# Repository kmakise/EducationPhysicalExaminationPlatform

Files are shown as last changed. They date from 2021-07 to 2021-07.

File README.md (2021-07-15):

# EducationPhysicalExaminationPlatform
基于STM32 RK3399的智能体检试验台 
## 上位
使用基于RK3399的Android工控平板作为交互终端
## 下位
使用基于STM32核FreeRTOS作为传感器驱动和数据上传
## 传感器
非接触式温度传感器：MLX90615
距离传感器： 夏普红外GP2Y0A
血氧浓度传感器：MAX30100
称重传感器：HX711+RB
烟雾触传感器：MQ-2
环境温湿度传感器:DHT11
光照度传感器：BH1750

# 图片
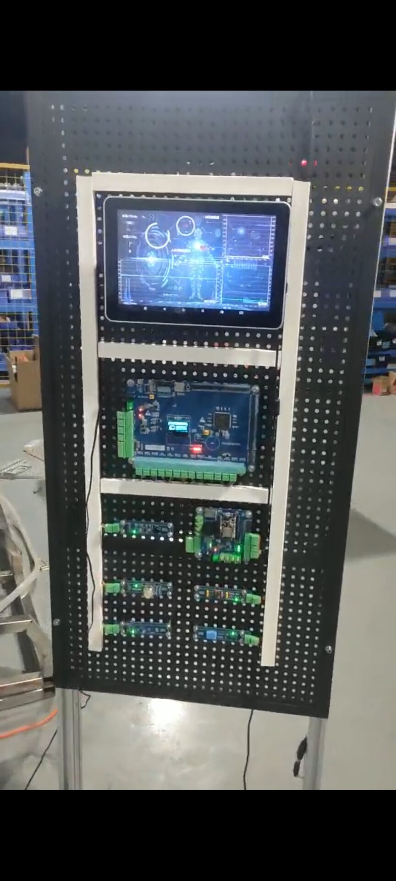
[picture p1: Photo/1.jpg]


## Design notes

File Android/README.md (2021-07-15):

# USB-OTG-CH340-UART-interface

USB-OTG-CH340-UART-interface that is a library communication with USB convert uart, that module is ch340 model, it not need root of your phone.

## License

```
   Copyright (C) [2018] [x-sir, USB-OTG-CH340-UART-interface Open Source Project]

   Licensed under the Apache License, Version 2.0 (the "License");
   you may not use this file except in compliance with the License.
   You may obtain a copy of the License at

       http://www.apache.org/licenses/LICENSE-2.0

   Unless required by applicable law or agreed to in writing, software
   distributed under the License is distributed on an "AS IS" BASIS,
   WITHOUT WARRANTIES OR CONDITIONS OF ANY KIND, either express or implied.
   See the License for the specific language governing permissions and
   limitations under the License.

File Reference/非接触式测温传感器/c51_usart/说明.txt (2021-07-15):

/*
Keil:uVision2
MCU:STC90C516RD+
硬件接法：
GY-MCU90614---STM32
1、GY-MCU90614_RX---STM32_TX,STM32复位将发送A5 45 EA给模块
2、STM32_TX---FT232,STM32将数据上传给上位机
3、GY-MCU90614_TX---STM32_RX，接收模块温度数据
软件说明:
该程序采用串口方式获取模块角度数据，波特率9600
所以得用上位机先将模块串口设置成9600，然后再进行以上操作：
指令:A5 AE 53,模块需复位生效

注：中断函数位于stc_it.c
联系方式：
http://shop62474960.taobao.com/?spm=a230r.7195193.1997079397.2.9qa3Ky&v=1

15.6.27
*/

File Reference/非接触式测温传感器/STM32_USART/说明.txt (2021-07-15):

/*
Keil: MDK5.10.0.2
MCU:stm32f103c8
硬件接法：
GY-MCU90614---STM32
1、GY-MCU90614_RX---STM32_TX,STM32复位将发送A5 45 EA给模块
2、STM32_TX---FT232,STM32将数据上传给上位机
3、GY-MCU90614_TX---STM32_RX，接收模块温度数据
软件说明:
该程序采用串口方式获取模块角度数据，波特率115200,
需要先修改模块或者单片机波特率对应一致。

联系方式：
http://shop62474960.taobao.com/?spm=a230r.7195193.1997079397.2.9qa3Ky&v=1
注：中断函数位于stm32f10x_it.c
15.6.27
*/

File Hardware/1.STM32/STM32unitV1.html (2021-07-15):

Altium customize

# Board Information Report

Date: | | 2021/1/8
Time: | | 13:16:20
Elapsed Time: | | 00:00:01
Filename: | | C:\Users\17122\Desktop\教学仪器\PCB\1.STM32-主控单元\STM32unit\STM32unitV1.PcbDoc
Units: | | mmmils

## Contents

Contents

Board Specification

General

Routing

Routing Information

Layer Information

Layer Information

Drill Pairs

Copper Area

Copper Area

Board Holes

Non-Plated Hole Size

Plated Hole Size

Board Slots

Non-Plated Slot Size

Plated Slot Size

Board Square Holes

Non-Plated Square Hole Size

Plated Square Hole Size

Other

Top Layer Annular Ring Size

Mid Layer Annular Ring Size

Bottom Layer Annular Ring Size

Pad Solder Mask

Pad Paste Mask

Pad Pwr/Gnd Expansion

Pad Relief Conductor Width

Pad Relief Air Gap

Pad Relief Entries

Via Solder Mask

Via Pwr/Gnd Expansion

Track Width

Arc Line Width

Arc Radius

Arc Degrees

Text Height

Text Width

Net Track Width

Net Via Size

## Board Specification

General
Board Size | 206mm x 142mm
Components on board | 234

Back to top

## Routing

Routing Information
Routing completion | 100.00%
Connections | 692
Connections routed | 692
Connections remaining | 0

Back to top

## Layer Information

Layer | Arcs | Pads | Vias | Tracks | Texts | Fills | Regions | ComponentBodies
Top Layer | 0 | 617 | 0 | 2739 | 0 | 0 | 65 | 0
Bottom Layer | 0 | 0 | 0 | 732 | 0 | 0 | 11 | 0
Mechanical 1 | 2 | 0 | 0 | 0 | 0 | 0 | 0 | 36
Mechanical 8 | 0 | 0 | 0 | 0 | 0 | 0 | 0 | 2
Mechanical 13 | 1742 | 0 | 0 | 32 | 0 | 0 | 0 | 225
Mechanical 15 | 169 | 0 | 0 | 370 | 0 | 0 | 0 | 0
Multi-Layer | 0 | 309 | 892 | 0 | 0 | 0 | 1 | 0
Top Paste | 0 | 4 | 0 | 0 | 0 | 0 | 0 | 0
Top Overlay | 40 | 0 | 0 | 2114 | 683 | 42 | 0 | 0
Top Solder | 0 | 0 | 0 | 0 | 0 | 0 | 0 | 0
Bottom Solder | 0 | 0 | 0 | 0 | 0 | 0 | 0 | 0
Bottom Overlay | 0 | 0 | 0 | 4 | 0 | 0 | 0 | 0
Bottom Paste | 0 | 0 | 0 | 0 | 0 | 0 | 0 | 0
Drill Guide | 0 | 0 | 0 | 0 | 0 | 0 | 0 | 0
Keep-Out Layer | 4 | 0 | 0 | 4 | 0 | 0 | 0 | 0
Drill Drawing | 0 | 0 | 0 | 0 | 0 | 0 | 0 | 0
Total | 1957 | 930 | 892 | 5995 | 683 | 42 | 77 | 263

Back to top

Drill Pairs | Vias
Top Layer - Bottom Layer | 892
Total | 892

Back to top

## Copper Area

Layer | Sq.In. | Sq.MM. | Percent of layer
Top Layer | 36.196 | 23351.938 | 80%
Bottom Layer | 41.461 | 26749.029 | 92%
Total | 77.657 | 50100.967

Back to top

## Board Holes

Non-Plated Hole Size | Pads | Vias
0.75mm | 2 | 0
Total | 2 | 0

Back to top

Plated Hole Size | Pads | Vias
0mm | 614 | 0
0.3mm | 0 | 862
0.6mm | 2 | 0
0.711mm | 0 | 30
0.85mm | 2 | 0
0.9mm | 202 | 0
1.1mm | 84 | 0
1.2mm | 2 | 0
1.27mm | 2 | 0
5.2mm | 4 | 0
Total | 912 | 892

Back to top

## Board Slots

Non-Plated Slot Size / Length | Pads
Total | 0

Back to top

Plated Slot Size / Length | Pads
23.622mil / 51.181mil | 2
31.496mil / 55.118mil | 2
31.496mil / 62.991mil | 1
31.496mil / 62.993mil | 1
31.496mil / 118.11mil | 1
31.496mil / 98.425mil | 1
31.496mil / 118.11mil | 1
Total | 9

Back to top

## Board Square Holes

Non-Plated Square Hole Size | Pads
Total | 0

Back to top

Plated Square Hole Size | Pads
Total | 0

Back to top

## Other

Top Layer Annular Ring Size | Count
0mm | 2
0.3mm | 862
0.4mm | 4
0.42mm | 2
0.559mm | 30
0.6mm | 144
0.7mm | 8
0.7mm | 2
0.8mm | 48
0.9mm | 2
0.9mm | 84
1.15mm | 2
1.2mm | 1
1.2mm | 1
1.3mm | 2
3.2mm | 1
3.81mm | 2
6.8mm | 4
Total | 1201

Back to top

Mid Layer Annular Ring Size | Count
0mm | 2
0.3mm | 862
0.4mm | 4
0.42mm | 2
0.559mm | 30
0.6mm | 144
0.7mm | 8
0.7mm | 2
0.8mm | 48
0.9mm | 2
0.9mm | 84
1.15mm | 2
1.2mm | 1
1.2mm | 1
1.3mm | 2
3.2mm | 1
3.81mm | 2
6.8mm | 4
Total | 1201

Back to top

Bottom Layer Annular Ring Size | Count
0mm | 2
0.3mm | 862
0.4mm | 4
0.42mm | 2
0.559mm | 30
0.6mm | 144
0.7mm | 8
0.7mm | 2
0.8mm | 48
0.9mm | 2
0.9mm | 84
1.15mm | 2
1.2mm | 1
1.2mm | 1
1.3mm | 2
3.2mm | 1
3.81mm | 2
6.8mm | 4
Total | 1201

Back to top

Pad Solder Mask | Count
0.1016mm | 930
Total | 930

Back to top

Pad Paste Mask | Count
0mm | 930
Total | 930

Back to top

Pad Pwr/Gnd Expansion | Count
0.508mm | 930
Total | 930

Back to top

Pad Relief Conductor Width | Count
0.254mm | 930
Total | 930

Back to top

Pad Relief Air Gap | Count
0.254mm | 930
Total | 930

Back to top

Pad Relief Entries | Count
4 | 930
Total | 930

Back to top

Via Solder Mask | Count
0.0254mm | 892
Total | 892

Back to top

Via Pwr/Gnd Expansion | Count
0.508mm | 892
Total | 892

Back to top

Track Width | Count
0.0254mm | 50
0.05mm | 292
0.1mm | 52
0.127mm | 50
0.129mm | 2
0.15mm | 4
0.1524mm | 820
0.2mm | 408
0.2032mm | 435
0.254mm | 3514
0.3048mm | 1
0.35mm | 1
0.381mm | 2
0.6mm | 16
0.8mm | 326
2mm | 6
2.54mm | 16
Total | 5995

Back to top

Arc Line Width | Count
0.0254mm | 25
0.05mm | 144
0.1mm | 1
0.127mm | 2
0.129mm | 1
0.15mm | 1
0.2mm | 1762
0.2032mm | 4
0.25mm | 8
0.254mm | 7
0.5mm | 1
0.6mm | 1
Total | 1957

Back to top

Arc Radius | Count
0.1016mm | 1
0.1136mm | 1
0.125mm | 8
0.127mm | 25
0.1545mm | 1
0.2016mm | 1
0.3mm | 1
0.35mm | 144
0.3592mm | 1
0.381mm | 2
0.5mm | 4
0.508mm | 2
1.1903mm | 16
2.2468mm | 1
2.325mm | 2
2.3899mm | 1
3mm | 1740
4.6mm | 1
7mm | 2
7mm | 2
10.8509mm | 1
Total | 1957

Back to top

Arc Degrees | Count
45 | 1
90 | 6
100 | 16
180 | 2
182 | 2
360 | 1930
Total | 1957

Back to top

Text Height | Count
1.27mm | 2
1.524mm | 470
2mm | 2
2.3mm | 2
2.54mm | 169
3mm | 7
3.5mm | 29
4mm | 1
5mm | 1
Total | 683

Back to top

Text Width | Count
0.1016mm | 2
0.1524mm | 4
0.254mm | 677
Total | 683

Back to top

Net Track Width | Count
0.127mm | 216
Total | 216

Back to top

Net Via Size | Count
0.6mm | 216
Total | 216

Back to top

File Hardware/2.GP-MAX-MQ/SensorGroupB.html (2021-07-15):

Altium customize

# Board Information Report

Date: | | 2021/1/14
Time: | | 15:26:07
Elapsed Time: | | 00:00:01
Filename: | | C:\Users\17122\Desktop\教学仪器\PCB\GP-MAX-MQ\SensorGroupB.PcbDoc
Units: | | mmmils

## Contents

Contents

Board Specification

General

Routing

Routing Information

Layer Information

Layer Information

Drill Pairs

Copper Area

Copper Area

Board Holes

Non-Plated Hole Size

Plated Hole Size

Board Slots

Non-Plated Slot Size

Plated Slot Size

Board Square Holes

Non-Plated Square Hole Size

Plated Square Hole Size

Other

Top Layer Annular Ring Size

Mid Layer Annular Ring Size

Bottom Layer Annular Ring Size

Pad Solder Mask

Pad Paste Mask

Pad Pwr/Gnd Expansion

Pad Relief Conductor Width

Pad Relief Air Gap

Pad Relief Entries

Via Solder Mask

Via Pwr/Gnd Expansion

Track Width

Arc Line Width

Arc Radius

Arc Degrees

Text Height

Text Width

Net Track Width

Net Via Size

## Board Specification

General
Board Size | 99.5mm x 79mm
Components on board | 24

Back to top

## Routing

Routing Information
Routing completion | 90.91%
Connections | 55
Connections routed | 50
Connections remaining | 5

Back to top

## Layer Information

Layer | Arcs | Pads | Vias | Tracks | Texts | Fills | Regions | ComponentBodies
Top Layer | 0 | 34 | 0 | 140 | 0 | 0 | 0 | 0
Bottom Layer | 0 | 0 | 0 | 9 | 0 | 0 | 3 | 0
Mechanical 1 | 0 | 0 | 0 | 0 | 0 | 0 | 0 | 6
Mechanical 13 | 0 | 0 | 0 | 0 | 0 | 0 | 0 | 32
Mechanical 15 | 10 | 0 | 0 | 20 | 0 | 0 | 0 | 0
Multi-Layer | 0 | 46 | 9 | 0 | 0 | 0 | 26 | 0
Top Paste | 0 | 0 | 0 | 0 | 0 | 0 | 0 | 0
Top Overlay | 7 | 0 | 0 | 272 | 102 | 6 | 0 | 0
Top Solder | 0 | 0 | 0 | 0 | 0 | 0 | 0 | 0
Bottom Solder | 0 | 0 | 0 | 0 | 0 | 0 | 0 | 0
Bottom Overlay | 0 | 0 | 0 | 0 | 0 | 0 | 0 | 0
Bottom Paste | 0 | 0 | 0 | 0 | 0 | 0 | 0 | 0
Drill Guide | 0 | 0 | 0 | 0 | 0 | 0 | 0 | 0
Keep-Out Layer | 37 | 0 | 0 | 24 | 0 | 0 | 0 | 0
Drill Drawing | 0 | 0 | 0 | 0 | 0 | 0 | 0 | 0
Total | 54 | 80 | 9 | 465 | 102 | 6 | 29 | 38

Back to top

Drill Pairs | Vias
Top Layer - Bottom Layer | 9
Total | 9

Back to top

## Copper Area

Layer | Sq.In. | Sq.MM. | Percent of layer
Top Layer | 0.992 | 640.177 | 8%
Bottom Layer | 4.947 | 3191.518 | 42%
Total | 5.939 | 3831.695

Back to top

## Board Holes

Non-Plated Hole Size | Pads | Vias
Total | 0 | 0

Back to top

Plated Hole Size | Pads | Vias
0mm | 34 | 0
0.7112mm | 0 | 9
0.9mm | 22 | 0
1.1mm | 12 | 0
5.2mm | 12 | 0
Total | 80 | 9

Back to top

## Board Slots

Non-Plated Slot Size / Length | Pads
Total | 0

Back to top

Plated Slot Size / Length | Pads
Total | 0

Back to top

## Board Square Holes

Non-Plated Square Hole Size | Pads
Total | 0

Back to top

Plated Square Hole Size | Pads
Total | 0

Back to top

## Other

Top Layer Annular Ring Size | Count
0.5588mm | 9
0.8mm | 22
0.9mm | 12
2.8mm | 12
Total | 55

Back to top

Mid Layer Annular Ring Size | Count
0.5588mm | 9
0.8mm | 22
0.9mm | 12
2.8mm | 12
Total | 55

Back to top

Bottom Layer Annular Ring Size | Count
0.5588mm | 9
0.8mm | 22
0.9mm | 12
2.8mm | 12
Total | 55

Back to top

Pad Solder Mask | Count
0.1016mm | 80
Total | 80

Back to top

Pad Paste Mask | Count
0mm | 80
Total | 80

Back to top

Pad Pwr/Gnd Expansion | Count
0.508mm | 80
Total | 80

Back to top

Pad Relief Conductor Width | Count
0.254mm | 80
Total | 80

Back to top

Pad Relief Air Gap | Count
0.254mm | 80
Total | 80

Back to top

Pad Relief Entries | Count
4 | 80
Total | 80

Back to top

Via Solder Mask | Count
0.0254mm | 9
Total | 9

Back to top

Via Pwr/Gnd Expansion | Count
0.508mm | 9
Total | 9

Back to top

Track Width | Count
0.0254mm | 2
0.05mm | 18
0.1524mm | 111
0.2mm | 32
0.2032mm | 6
0.254mm | 147
0.381mm | 149
Total | 465

Back to top

Arc Line Width | Count
0.0254mm | 1
0.05mm | 9
0.2mm | 6
0.254mm | 37
1mm | 1
Total | 54

Back to top

Arc Radius | Count
0.127mm | 1
0.35mm | 9
0.508mm | 1
1.1981mm | 2
1.5mm | 6
1.6mm | 18
2mm | 2
3mm | 1
3.5mm | 2
4mm | 12
Total | 54

Back to top

Arc Degrees | Count
90 | 12
180 | 2
360 | 40
Total | 54

Back to top

Text Height | Count
1.27mm | 3
1.524mm | 48
2mm | 27
3mm | 12
4mm | 8
6mm | 4
Total | 102

Back to top

Text Width | Count
0.1524mm | 3
0.254mm | 99
Total | 102

Back to top

Net Track Width | Count
0.127mm | 13
Total | 13

Back to top

Net Via Size | Count
0.6mm | 13
Total | 13

Back to top

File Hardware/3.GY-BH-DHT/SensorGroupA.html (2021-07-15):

Altium customize

# Board Information Report

Date: | | 2021/1/13
Time: | | 20:07:42
Elapsed Time: | | 00:00:01
Filename: | | C:\Users\17122\Desktop\教学仪器\PCB\2.体温-温湿度-光照\GY-BH-DHT\SensorGroupA.PcbDoc
Units: | | mmmils

## Contents

Contents

Board Specification

General

Routing

Routing Information

Layer Information

Layer Information

Drill Pairs

Copper Area

Copper Area

Board Holes

Non-Plated Hole Size

Plated Hole Size

Board Slots

Non-Plated Slot Size

Plated Slot Size

Board Square Holes

Non-Plated Square Hole Size

Plated Square Hole Size

Other

Top Layer Annular Ring Size

Mid Layer Annular Ring Size

Bottom Layer Annular Ring Size

Pad Solder Mask

Pad Paste Mask

Pad Pwr/Gnd Expansion

Pad Relief Conductor Width

Pad Relief Air Gap

Pad Relief Entries

Via Solder Mask

Via Pwr/Gnd Expansion

Track Width

Arc Line Width

Arc Radius

Arc Degrees

Text Height

Text Width

Net Track Width

Net Via Size

## Board Specification

General
Board Size | 99.5mm x 79mm
Components on board | 47

Back to top

## Routing

Routing Information
Routing completion | 95.28%
Connections | 106
Connections routed | 101
Connections remaining | 5

Back to top

## Layer Information

Layer | Arcs | Pads | Vias | Tracks | Texts | Fills | Regions | ComponentBodies
Top Layer | 0 | 103 | 0 | 306 | 0 | 0 | 0 | 0
Bottom Layer | 0 | 0 | 0 | 34 | 0 | 0 | 3 | 0
Mechanical 1 | 0 | 0 | 0 | 0 | 0 | 0 | 0 | 6
Mechanical 13 | 1 | 0 | 0 | 44 | 0 | 0 | 0 | 51
Mechanical 15 | 25 | 0 | 0 | 78 | 0 | 0 | 0 | 0
Multi-Layer | 0 | 46 | 38 | 0 | 0 | 0 | 19 | 0
Top Paste | 0 | 0 | 0 | 0 | 0 | 0 | 0 | 0
Top Overlay | 24 | 0 | 0 | 429 | 143 | 6 | 0 | 0
Top Solder | 0 | 0 | 0 | 0 | 0 | 0 | 0 | 0
Bottom Solder | 0 | 0 | 0 | 0 | 0 | 0 | 0 | 0
Bottom Overlay | 0 | 0 | 0 | 0 | 0 | 0 | 0 | 0
Bottom Paste | 0 | 0 | 0 | 0 | 0 | 0 | 0 | 0
Drill Guide | 0 | 0 | 0 | 0 | 0 | 0 | 0 | 0
Keep-Out Layer | 30 | 0 | 0 | 24 | 0 | 0 | 0 | 0
Drill Drawing | 0 | 0 | 0 | 0 | 0 | 0 | 0 | 0
Total | 80 | 149 | 38 | 915 | 143 | 6 | 22 | 57

Back to top

Drill Pairs | Vias
Top Layer - Bottom Layer | 38
Total | 38

Back to top

## Copper Area

Layer | Sq.In. | Sq.MM. | Percent of layer
Top Layer | 1.251 | 806.835 | 11%
Bottom Layer | 5.044 | 3254.363 | 43%
Total | 6.295 | 4061.198

Back to top

## Board Holes

Non-Plated Hole Size | Pads | Vias
Total | 0 | 0

Back to top

Plated Hole Size | Pads | Vias
0mm | 103 | 0
0.3mm | 0 | 36
0.7112mm | 0 | 2
0.8mm | 4 | 0
0.9mm | 18 | 0
1.1mm | 12 | 0
5.2mm | 12 | 0
Total | 149 | 38

Back to top

## Board Slots

Non-Plated Slot Size / Length | Pads
Total | 0

Back to top

Plated Slot Size / Length | Pads
Total | 0

Back to top

## Board Square Holes

Non-Plated Square Hole Size | Pads
Total | 0

Back to top

Plated Square Hole Size | Pads
Total | 0

Back to top

## Other

Top Layer Annular Ring Size | Count
0.3mm | 36
0.5588mm | 2
0.6mm | 4
0.8mm | 18
0.9mm | 12
2.8mm | 12
Total | 84

Back to top

Mid Layer Annular Ring Size | Count
0.3mm | 36
0.5588mm | 2
0.6mm | 4
0.8mm | 18
0.9mm | 12
2.8mm | 12
Total | 84

Back to top

Bottom Layer Annular Ring Size | Count
0.3mm | 36
0.5588mm | 2
0.6mm | 4
0.8mm | 18
0.9mm | 12
2.8mm | 12
Total | 84

Back to top

Pad Solder Mask | Count
0.1016mm | 149
Total | 149

Back to top

Pad Paste Mask | Count
0mm | 149
Total | 149

Back to top

Pad Pwr/Gnd Expansion | Count
0.508mm | 149
Total | 149

Back to top

Pad Relief Conductor Width | Count
0.254mm | 149
Total | 149

Back to top

Pad Relief Air Gap | Count
0.254mm | 149
Total | 149

Back to top

Pad Relief Entries | Count
4 | 149
Total | 149

Back to top

Via Solder Mask | Count
0.0254mm | 38
Total | 38

Back to top

Via Pwr/Gnd Expansion | Count
0.508mm | 38
Total | 38

Back to top

Track Width | Count
0.01mm | 32
0.0254mm | 12
0.05mm | 42
0.1mm | 16
0.127mm | 22
0.1524mm | 129
0.2mm | 56
0.2032mm | 73
0.254mm | 373
0.3mm | 8
0.6mm | 152
Total | 915

Back to top

Arc Line Width | Count
0.0254mm | 6
0.05mm | 19
0.2mm | 22
0.25mm | 3
0.254mm | 30
Total | 80

Back to top

Arc Radius | Count
0.1mm | 2
0.125mm | 3
0.127mm | 6
0.3023mm | 1
0.35mm | 19
0.6839mm | 1
0.699mm | 16
1.6mm | 18
2.218mm | 1
4mm | 12
5.1mm | 1
Total | 80

Back to top

Arc Degrees | Count
90 | 12
142 | 16
180 | 1
316 | 1
360 | 50
Total | 80

Back to top

Text Height | Count
1.27mm | 3
1.524mm | 94
2mm | 33
2.54mm | 3
3mm | 7
6mm | 3
Total | 143

Back to top

Text Width | Count
0.1524mm | 3
0.254mm | 140
Total | 143

Back to top

Net Track Width | Count
0.127mm | 19
Total | 19

Back to top

Net Via Size | Count
0.6mm | 19
Total | 19

Back to top

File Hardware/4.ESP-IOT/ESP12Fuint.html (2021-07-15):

Altium customize

# Board Information Report

Date: | | 2021/1/15
Time: | | 15:26:02
Elapsed Time: | | 00:00:01
Filename: | | C:\Users\17122\Desktop\教学仪器\PCB\4.ESP-IOT\ESP12Fuint.PcbDoc
Units: | | mmmils

## Contents

Contents

Board Specification

General

Routing

Routing Information

Layer Information

Layer Information

Drill Pairs

Copper Area

Copper Area

Board Holes

Non-Plated Hole Size

Plated Hole Size

Board Slots

Non-Plated Slot Size

Plated Slot Size

Board Square Holes

Non-Plated Square Hole Size

Plated Square Hole Size

Other

Top Layer Annular Ring Size

Mid Layer Annular Ring Size

Bottom Layer Annular Ring Size

Pad Solder Mask

Pad Paste Mask

Pad Pwr/Gnd Expansion

Pad Relief Conductor Width

Pad Relief Air Gap

Pad Relief Entries

Via Solder Mask

Via Pwr/Gnd Expansion

Track Width

Arc Line Width

Arc Radius

Arc Degrees

Text Height

Text Width

Net Track Width

Net Via Size

## Board Specification

General
Board Size | 93mm x 93mm
Components on board | 97

Back to top

## Routing

Routing Information
Routing completion | 100.00%
Connections | 233
Connections routed | 233
Connections remaining | 0

Back to top

## Layer Information

Layer | Arcs | Pads | Vias | Tracks | Texts | Fills | Regions | ComponentBodies
Top Layer | 0 | 175 | 0 | 679 | 0 | 0 | 22 | 0
Bottom Layer | 0 | 0 | 0 | 55 | 0 | 0 | 2 | 0
Mechanical 1 | 2 | 0 | 0 | 0 | 0 | 0 | 0 | 16
Mechanical 8 | 0 | 0 | 0 | 0 | 0 | 0 | 0 | 1
Mechanical 13 | 1 | 0 | 0 | 20 | 0 | 0 | 0 | 97
Mechanical 15 | 60 | 0 | 0 | 147 | 0 | 0 | 0 | 0
Multi-Layer | 0 | 132 | 145 | 0 | 0 | 0 | 1 | 0
Top Paste | 0 | 0 | 0 | 0 | 0 | 0 | 0 | 0
Top Overlay | 13 | 0 | 0 | 899 | 263 | 23 | 0 | 0
Top Solder | 0 | 0 | 0 | 0 | 0 | 0 | 0 | 0
Bottom Solder | 0 | 0 | 0 | 0 | 0 | 0 | 0 | 0
Bottom Overlay | 0 | 0 | 0 | 0 | 0 | 0 | 0 | 0
Bottom Paste | 0 | 0 | 0 | 0 | 0 | 0 | 0 | 0
Drill Guide | 0 | 0 | 0 | 0 | 0 | 0 | 0 | 0
Keep-Out Layer | 4 | 0 | 0 | 4 | 0 | 0 | 0 | 0
Drill Drawing | 0 | 0 | 0 | 0 | 0 | 0 | 0 | 0
Total | 80 | 307 | 145 | 1804 | 263 | 23 | 25 | 114

Back to top

Drill Pairs | Vias
Top Layer - Bottom Layer | 145
Total | 145

Back to top

## Copper Area

Layer | Sq.In. | Sq.MM. | Percent of layer
Top Layer | 10.28 | 6632.221 | 77%
Bottom Layer | 11.59 | 7477.441 | 87%
Total | 21.87 | 14109.662

Back to top

## Board Holes

Non-Plated Hole Size | Pads | Vias
Total | 0 | 0

Back to top

Plated Hole Size | Pads | Vias
0mm | 175 | 0
0.3mm | 0 | 139
0.711mm | 0 | 6
0.9mm | 86 | 0
1.1mm | 24 | 0
1.2mm | 8 | 0
1.27mm | 2 | 0
1.6mm | 5 | 0
5.2mm | 4 | 0
Total | 304 | 145

Back to top

## Board Slots

Non-Plated Slot Size / Length | Pads
Total | 0

Back to top

Plated Slot Size / Length | Pads
31.496mil / 118.11mil | 1
31.496mil / 98.425mil | 1
31.496mil / 118.11mil | 1
Total | 3

Back to top

## Board Square Holes

Non-Plated Square Hole Size | Pads
Total | 0

Back to top

Plated Square Hole Size | Pads
Total | 0

Back to top

## Other

Top Layer Annular Ring Size | Count
0.3mm | 139
0.559mm | 6
0.6mm | 60
0.8mm | 26
0.9mm | 24
1.2mm | 9
1.2mm | 1
1.4mm | 5
3.2mm | 1
3.81mm | 2
6.8mm | 4
Total | 277

Back to top

Mid Layer Annular Ring Size | Count
0.3mm | 139
0.559mm | 6
0.6mm | 60
0.8mm | 26
0.9mm | 24
1.2mm | 9
1.2mm | 1
1.4mm | 5
3.2mm | 1
3.81mm | 2
6.8mm | 4
Total | 277

Back to top

Bottom Layer Annular Ring Size | Count
0.3mm | 139
0.559mm | 6
0.6mm | 60
0.8mm | 26
0.9mm | 24
1.2mm | 9
1.2mm | 1
1.4mm | 5
3.2mm | 1
3.81mm | 2
6.8mm | 4
Total | 277

Back to top

Pad Solder Mask | Count
0.1016mm | 307
Total | 307

Back to top

Pad Paste Mask | Count
0mm | 307
Total | 307

Back to top

Pad Pwr/Gnd Expansion | Count
0.508mm | 307
Total | 307

Back to top

Pad Relief Conductor Width | Count
0.254mm | 232
0.4mm | 75
Total | 307

Back to top

Pad Relief Air Gap | Count
0.254mm | 307
Total | 307

Back to top

Pad Relief Entries | Count
4 | 307
Total | 307

Back to top

Via Solder Mask | Count
0.0254mm | 145
Total | 145

Back to top

Via Pwr/Gnd Expansion | Count
0.508mm | 145
Total | 145

Back to top

Track Width | Count
0.0254mm | 4
0.05mm | 116
0.1mm | 38
0.127mm | 20
0.15mm | 29
0.1524mm | 325
0.2mm | 215
0.2032mm | 159
0.254mm | 775
0.3048mm | 1
0.35mm | 1
0.381mm | 1
0.6mm | 56
0.8mm | 37
1mm | 12
2mm | 15
Total | 1804

Back to top

Arc Line Width | Count
0.0254mm | 2
0.05mm | 58
0.127mm | 1
0.2mm | 8
0.25mm | 4
0.254mm | 6
0.5mm | 1
Total | 80

Back to top

Arc Radius | Count
0.125mm | 4
0.127mm | 2
0.2016mm | 1
0.2176mm | 3
0.25mm | 1
0.35mm | 58
0.381mm | 2
0.5mm | 3
2.2468mm | 1
2.3899mm | 1
6.5mm | 4
Total | 80

Back to top

Arc Degrees | Count
45 | 1
90 | 4
180 | 1
360 | 74
Total | 80

Back to top

Text Height | Count
1mm | 33
1.2mm | 30
1.27mm | 1
1.5mm | 7
1.524mm | 178
2mm | 11
2.3mm | 2
3mm | 1
Total | 263

Back to top

Text Width | Count
0.1016mm | 2
0.15mm | 1
0.1524mm | 1
0.254mm | 259
Total | 263

Back to top

Net Track Width | Count
0.127mm | 68
Total | 68

Back to top

Net Via Size | Count
0.6mm | 68
Total | 68

Back to top

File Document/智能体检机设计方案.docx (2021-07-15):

# 智能体检机系统设计方案（拟）

## 一、设计意义

### 为促进教学模式改革，激发学生学习兴趣，满足专业教学需求，设计实现智能体检机系统，融入专业技术知识和核心课程，达成“学有所用，以用导学”的目的，进一步激发学生对专业课程学习的热情，引导学生学习方向。以该系统为载体，将课堂所学技术知识和实训所掌握的专业技能，实际运用到系统中，夯实专业知识，达成“学有所用”；在进行课程教学之前，通过对系统整体的认知和交互式体验，使得学生对专业有整体性认知，能合理规划自己未来成长方向，拓展学生知识面，达成“以用导学”，方便教师进行项目式教学。

## 二、功能支持

### （一）系统功能：

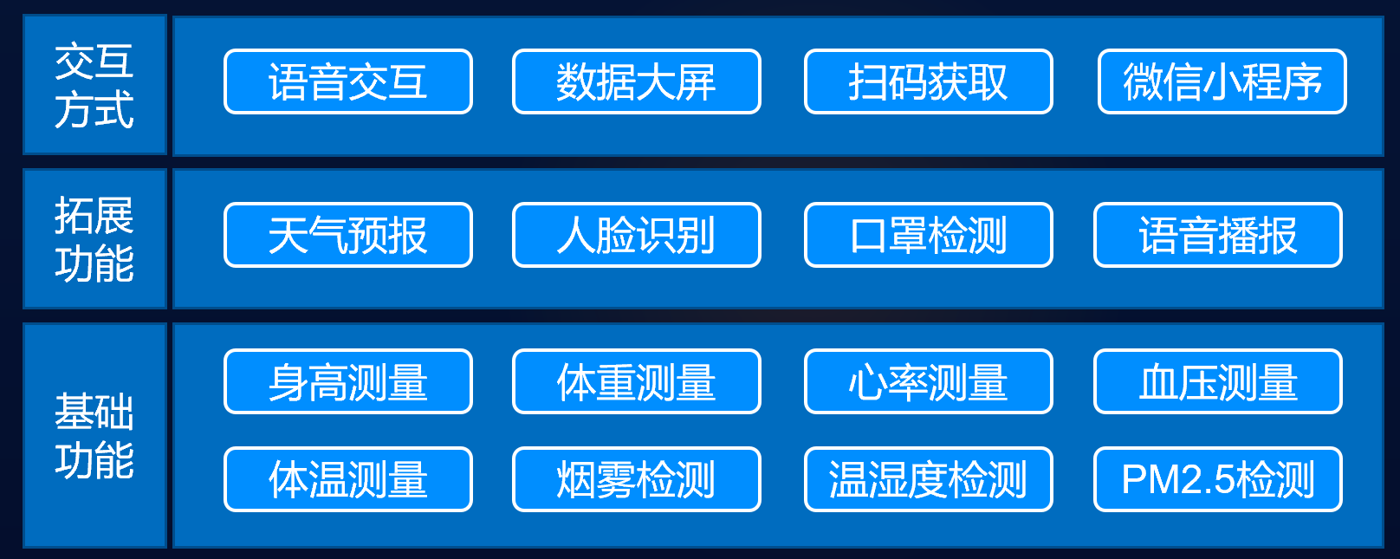
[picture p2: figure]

# 图 2-1 系统支持功能（拟）

### （二）课程支撑：

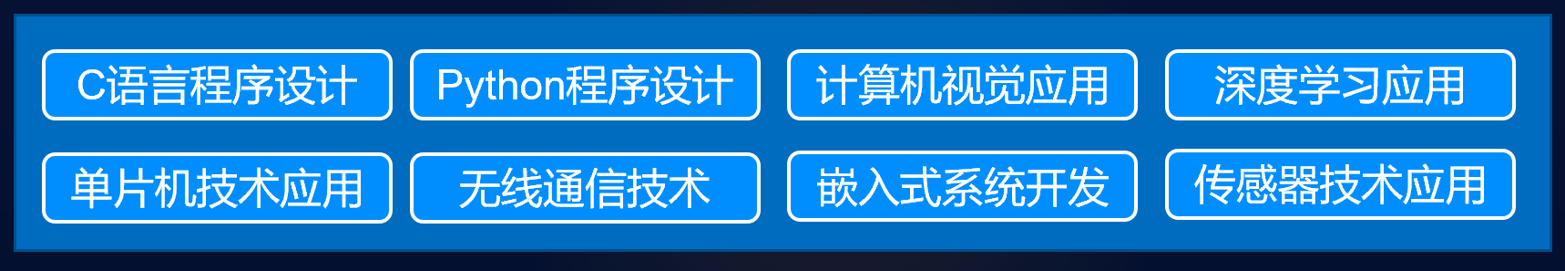
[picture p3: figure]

# 图 2-2 涉及课程

### 系统保留有开放式编程调试接口，支持二次开发和课程实训，并配备模块化实训套件配合使用。

## 三、设计思路

### （一）系统架构

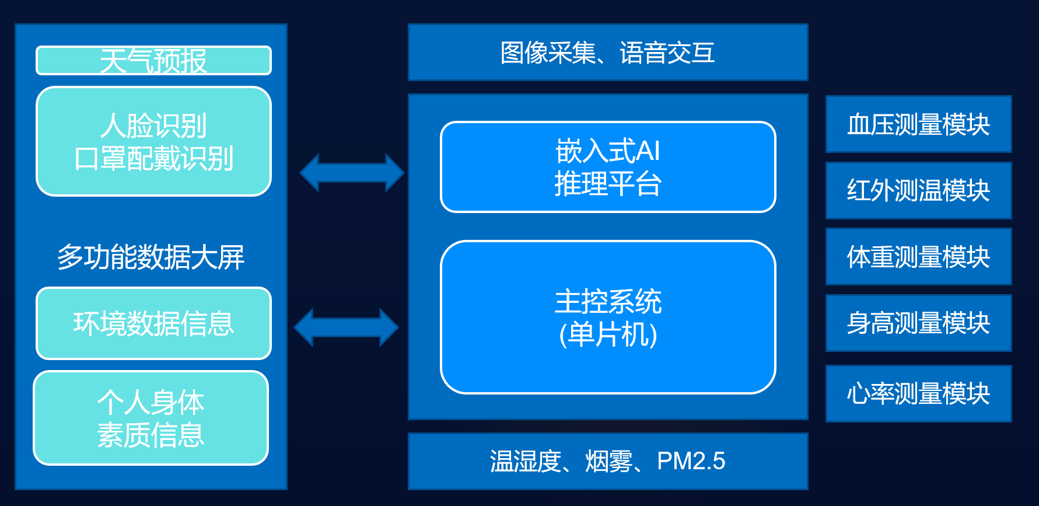
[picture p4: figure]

# 图 3-1 系统设计架构（拟）

### 系统以单片机为核心设计主控系统，采集外部传感器数据获取体重、体温、身高、心率、血压等身体素质信息，以及温湿度、烟雾、PM2.5浓度等环境信息，以嵌入式AI推理平台处理图像采集数据，完成人脸识别、口罩配戴识别等。数据大屏支持显示天气预报场景、人脸识别场景、口罩佩戴检测场景、环境数据可视化、身体素质信息可视化等场景。交互方式上可拓展语音交互、二维码、微信小程序等获取数据信息。（拟，缺乏技术元素）

### （二）实训结构设计

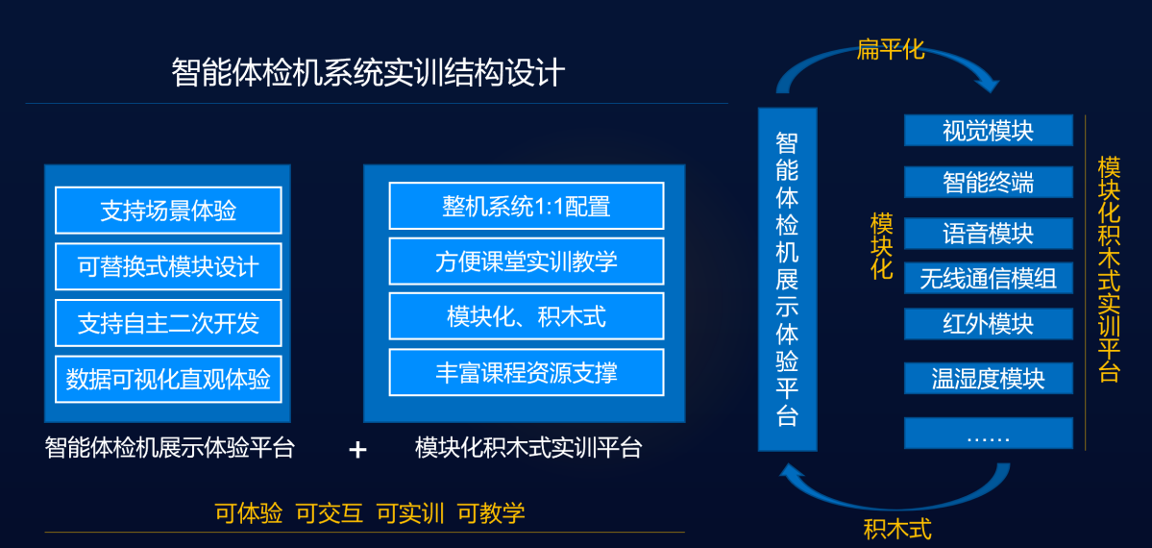
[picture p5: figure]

# 图 3-2 系统实训结构设计

系统实训架构采用“智能体检机展示平台+配套模块化积木式实训平台”设计模式，兼容展示体验和实训功能。“智能体检机展示平台”是“模块化积木式实训平台”的集成运用，支持场景式体验，可替换式模块设计，方便学生使用系统模块在课堂调试开发，然后装机调试，验证实训效果，“智能体检机展示平台”本身提供调试编程接口，为学生二次开发提供便利，数据可视化为展示体验带来震撼视觉效果，增强交互效果。“模块化积木式实训平台”是“智能体检机展示平台”搬进课堂的扁平化应用，“模块化积木式实训平台”以便捷实训为目标，按照“智能体检机展示平台”的模块架构，扁平化1:1还原，将“智能体检机展示平台”设计成多个实训案例，案例可单项使用，点对点精准化训练学生专项技能，也可组合式使用，设计各种场景应用，培养学生项目式思维。系统所涉及技术知识，可通过线上资源平台获取或者在线学习。

## 四、产品效果

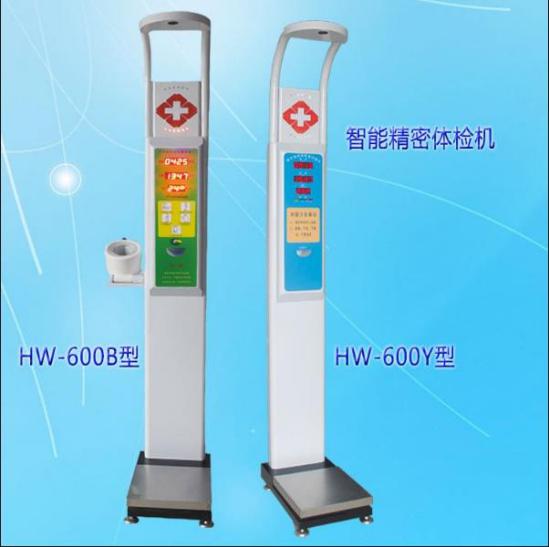
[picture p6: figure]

# 图 4-1 （参考图）

### 智能体检机展示平台（包含场地设计）、模块化实训平台（配件箱，参考智能车模块化积木式设计、阶梯化）、图纸（尺寸）等；

## 五、设备报价

### （15万~20万）

## 附件技术参数

序号 | 名称 | 设备详细参数

1

智能体检机系统

一、总体介绍

二、硬件资源及技术参数

1. 嵌入式AI推理平台

（1）边缘智能处理终端

1）AI性能：21 TOPS

2）GPU 384-core NVIDIA Volta™ GPU 和 48 Tensor Cores

3）CPU 6-core NVIDIA Carmel ARM®v8.2 64-bit CPU6MB L2 +

4MB L3

5）内存与存储：8 GB 128-bit LPDDR4x51.2GB/s，16 GB eMMC 5.1；

6）功耗：10 W|15 W

7）PCIe：1 x1 (PCIe Gen3) + 1 x4 (PCIe Gen4), total 144 GT/s*

最多6个摄像头（通过虚拟通道可以最多支持24个）

8) CSI摄像头 最多6个摄像头（通过虚拟通道可以最多支持24

个）14 lanes (3x4 or 6x2) MIPI CSI-2D-PHY 1.2 (up to 30 Gbps)

9） 视频编码：2x 4Kp30 | 6x 1080p60 | 14x 1080p30 (H.265 &

H.264)

10） 视频解码：2x 4Kp60 | 4x 4Kp30 | 12x 1080p60 | 32x 1080p30

(H.265)2x 4Kp30 | 6x 1080p60 | 16x 1080p30 (H.264)

11） 显示接口：2 multi-mode DP 1.4/eDP 1.4/HDMI 2.0
12） 深度学习加速器：2个 NVDLA 引擎
13） 视觉加速器：7路 VLIW 视觉处理器
14） 网络：10/100/1000 BASE-T Ethernet
15） 结构尺寸：69.6 mm x 45 mm260-pin SO-DIMMconnector

（2）大数据终端显示器

1）CPU：Intel I7

2）RAM：4G

3 硬盘：120G固态硬盘

4）系统：windows

5）显示：85英寸触摸一体机 YCZX

（3）机载嵌入显示器

1）显示屏：VVX10T025J00

2）分辨率：2K

3）尺寸：10.1寸

4）接口：2MINI HDMI

（4）图像获取单元

1）双目摄像头：Aoni S500

2）分辨率：2592x1944 2K

3）生物识别：双500万动态，红外2m范围

（5）音频单元

1）麦克风阵列：XHS2

2）语音技术：深度消除回音/动态噪声抑制/自动增益控制技术

3）麦克风频响：100Hz-8KHz

4）喇叭频：100Hz-22KHz

5）麦克风拾音范围：半径5米，360度全范围

6）喇叭音量：80db

(6)网络组网单元

1) 接口：USB

2）协议：2.4G，5G双频

3）速率：600Mbps

2. 核心控制单元

（1）STM32F4核心控制单元

1）采用STM32F407IGT6为核心处理器，主频可达168MHz；

2）内存和存储：1MB Flash，192KB SRAM；

3）板载资源及扩展接口：1路12V供电接口，1路硬件复位按键，1路电源管理模块接口，4个功能按键，4个LED灯，1路任务板接口，1路循迹板接口，1路通信显示板接口，1路扩展板接口， 5路CAN总线接口，1个SD卡插槽，1路3.5寸TFT显示屏接口，1路RS485通信接口，1路4Pin串口，1路DAC接口。

（2）ESP32物联网单元

1)集成 ESP32-S2 芯片，Xtensa® 32-bit LX7 单核处理器，时钟频率高达 240 MHz。

2)支持多种低功耗工作状态：精细时钟门控、动态电压时钟频率调节。

3)安全机制：eFuse 存储、安全启动、Flash 加密、数字签名，支持 AES、SHA 和 RSA 算法。

4)外设包括 43 个 GPIO 口，1 个全速 USB OTG 接口，SPI，I2S，UART，I2C，LED PWM，LCD 接口，Camera 接口，ADC，DAC，触摸传感器。

5)通过 RF 认证以及软件协议认证。

3. 功能扩展单元

（1）功能扩展板V1

1）提供1路6P接口

2）提供4路3P功能扩展接口

3）提供1路4P串口

4）提供1路4P IIC通信接口

5）提供1路16P核心控制单元接口

（2）传感器单元

1）测距传感器单元

单元提供1个红外测距传感器（GP2Y0A21YK0F），测量范围10~80 cm，最大角度40°，更新频率25Hz，周期40ms。

3）压力传感器单元

单元提供4路压力传感器（YZC-161D/75KG），量程范围0-300kg，灵敏度1.0mV/1V，非线性0.08%，迟滞0.1%，零点漂移0.2%。

4） 血氧心率模块

单元提供一个血氧传感器（MAX30102），LED峰值波660nm/880nm

LED供电电压3.3~5V，输出信号：光反射信号PPG，输出接口：I2C，通信接口电压1.8~3.3~5V可选。

5） 非接触式测温模块

单元提供一个非接触测温传感器（GY-906 MLX90614ES）医用高精

度校准，供电电源：3-5v（内部低压差稳压），温度范围：-40-+125°C测量辨析度：0.02°C。

6）烟雾传感器单元

单元提供1路可燃气体浓度测量传感器（MQ-2），可检测液化气、丙烷、氢气等可燃气体，测量范围为300～10000ppm，测量精度≥5％，响应时间＜10s，恢复时间＜10s。

7）甲醛传感器单元

单元提供1路甲醛气体测量传感器（SGP30），可检测TVOC和CO2等室内有害气体，测量范围为400~60000ppm，测量误差15%，采样率1s，板载1路IIC通信接口。

8）温湿度传感器单元

单元提供1路已校准数字信号输出的温湿度传感器（DHT11），内部集成1个电阻式感湿元件和1个NTC测温元件，湿度量程20~90%RH，湿度精度±5%RH，温度量程0~50℃，温度精度±2℃。

9）光照度传感器单元

单元提供1路光照度测量传感器（BH1750），传感器内置16位高精度AD转换器，最小分辨率0.5 lx，最大可测量65535 lx，支持IIC总线通信。

10）空气污染检测传感器单元

单元提供1路空气质量测量传感器（MQ-135），工作电压2.5~5V，可检测氨气、甲苯、氢气等有害气体，测量浓度范围10~1000ppm，测量精度gas≥5（100ppm），浓度斜率＜0.6（50ppm）。

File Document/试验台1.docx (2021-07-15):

序号 | 名称 | 设备详细参数

1

智能体检机系统

一、总体介绍

二、硬件资源及技术参数

1. 工业控制交互平台

（1）工业显示处理终端

1）CPU：RockChip RK3399 Cortex-A53 4x Cortex-A72 2x 6core 1.8Ghz

2）RAM：2GB DDR3

3）LCD：10寸 电容触摸

4）显示：HDMI

5）内存：16G

6）接口：USARTx3，USBx3，GPIOx4，Audiox4，TF，SIM 4G，100M以太网，

7）系统：Android7.1

2. 核心控制单元

（1）STM32集成开发系统

1）采用STM32F407IGT6为核心处理器，主频可达168MHz；

2）内存和存储：1MB Flash，192KB SRAM；

3）板载资源及扩展接口：1路12V供电接口，1路硬件复位按键，1路电源管理模块接口，4个LED灯，10路舵机接口，1路接口，1路通信显示板接口，1路扩展板接口， 1路CAN总线接口，1个SD卡插槽，1路OLED显示屏接口，1路4Pin串口。

（2）ESP12物联网开发平台

1)集成 ESP12 芯片，Xtensa® 32-bit LX7 单核处理器，时钟频率高达 240 MHz。

2)支持多种低功耗工作状态：精细时钟门控、动态电压时钟频率调节。

3)安全机制：eFuse 存储、安全启动、Flash 加密、数字签名，支持 AES、SHA 和 RSA 算法。

4)外设包括 43 个 GPIO 口，1 个全速 USB OTG 接口，SPI，I2S，UART，I2C，LED PWM，LCD 接口，Camera 接口，ADC，DAC，触摸传感器。

5)通过 RF 认证以及软件协议认证。

3. 功能扩展单元

1）测距传感器单元

单元提供1个红外测距传感器（GP2Y0A21YK0F），测量范围10~80 cm，最大角度40°，更新频率25Hz，周期40ms。

3）压力传感器单元

单元提供4路压力传感器（YZC-161D/75KG），量程范围0-300kg，灵敏度1.0mV/1V，非线性0.08%，迟滞0.1%，零点漂移0.2%。

4） 血氧心率模块

单元提供一个血氧传感器（MAX30102），LED峰值波660nm/880nm

LED供电电压3.3~5V，输出信号：光反射信号PPG，输出接口：I2C，通信接口电压1.8~3.3~5V可选。

5） 非接触式测温模块

单元提供一个非接触测温传感器（GY-906 MLX90614ES）医用高精

度校准，供电电源：3-5v（内部低压差稳压），温度范围：-40-+125°C测量辨析度：0.02°C。

6）烟雾传感器单元

单元提供1路可燃气体浓度测量传感器（MQ-2），可检测液化气、丙烷、氢气等可燃气体，测量范围为300～10000ppm，测量精度≥5％，响应时间＜10s，恢复时间＜10s。

7）温湿度传感器单元

单元提供1路已校准数字信号输出的温湿度传感器（DHT11），内部集成1个电阻式感湿元件和1个NTC测温元件，湿度量程20~90%RH，湿度精度±5%RH，温度量程0~50℃，温度精度±2℃。

8）光照度传感器单元

单元提供1路光照度测量传感器（BH1750），传感器内置16位高精度AD转换器，最小分辨率0.5 lx，最大可测量65535 lx，支持IIC总线通信。

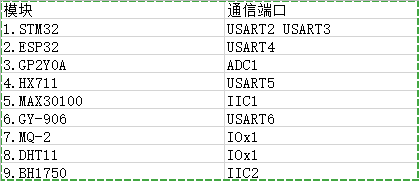
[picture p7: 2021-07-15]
Hardware/1.STM32/Port.png

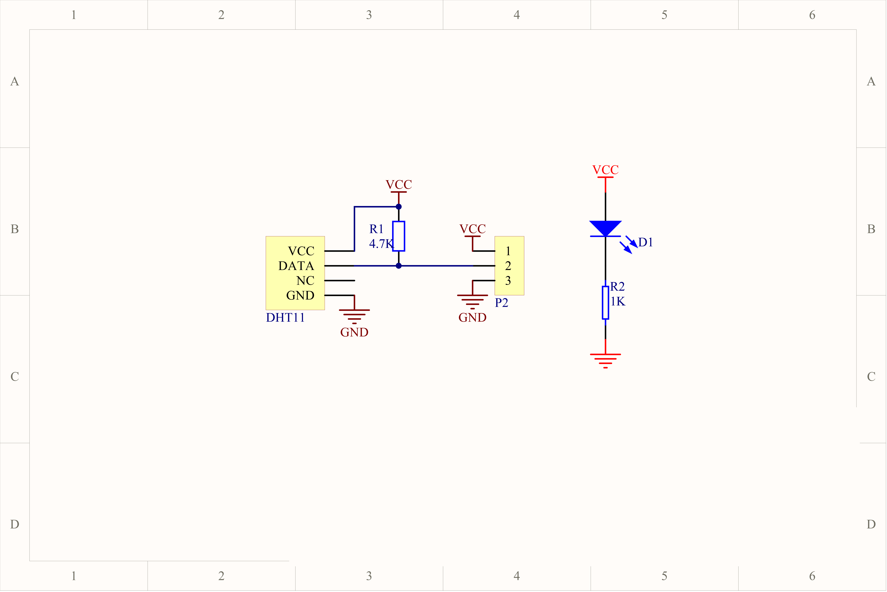
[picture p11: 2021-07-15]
Reference/环境温湿度传感器/YL-41 DHT11原理图/DHT11模块.jpg

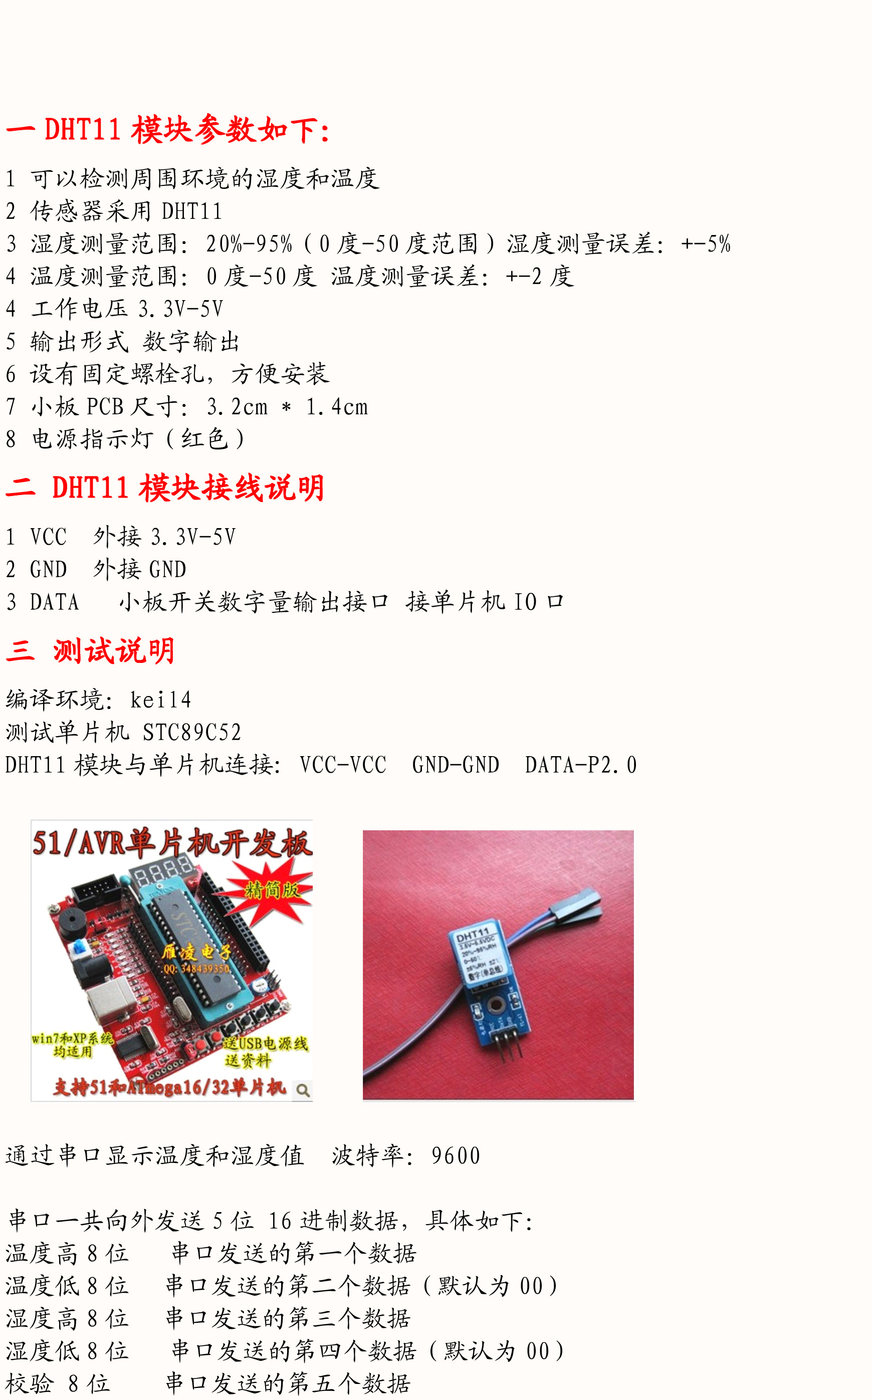
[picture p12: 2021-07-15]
Reference/环境温湿度传感器/YL-47 DHT11 使用‌说明书/YL-47 DHT11 使用说明-2.jpg

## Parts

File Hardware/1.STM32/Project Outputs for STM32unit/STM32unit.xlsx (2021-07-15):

Comment | Description | Designator | Footprint | LibRef | Quantity | Value
0603 |  | C1, C2 | C 0603_L | CAP | 2 | 20pF
0805 |  | C3 | C 0805_M | CAP | 1 | 1.0uF
0805 |  | C4, C5 | C 0805_M | CAP | 2 | 2.2uF
0805 |  | C6, C52, C53 | C 0805_M | CAP | 3 | 100nF
0603 |  | C7 | C 0603_M | CAP | 1 | 6.8pF
0603 |  | C8 | C 0603_L | CAP | 1 | 6.8pF
10uF | Capacitor | C9, C21 | 3528 | CAP-+ | 2
4.7uF/16V | Capacitor | C10, C12, C22, C24 | 0603C | CAP1 | 4
0.1uF | Capacitor | C11, C23 | 0603C | CAP1 | 2
1nF | Capacitor | C13, C25 | 0603C | CAP1 | 2
0805 |  | C14, C18 | C 0603_L | CAP | 2 | 0.1uF
0805 |  | C15, C19 | C 0603_L | CAP | 2 | 1uF
10uF/25V | Capacitor | C16, C26 | 1206 | CAP1 | 2
47pF | Capacitor | C17, C27 | 0603C | CAP1 | 2
10nF | Capacitor | C20, C28 | 0603C | CAP1 | 2
104 | 无极性贴片电容 | C29, C46, C48, C50 | C 0805 | C | 4
0805 |  | C30, C31, C32, C33, C34, C35, C36, C37, C38, C39, C40, C41, C42, C43, C44 | C 0603_L | CAP | 15 | 100nF
105 | 无极性贴片电容 | C45, C47, C49, C51 | C 0805 | C | 4
0805 |  | C54, C55 | C 0805_M | CAP | 2 | 330pF
0805 |  | C57, C58 | C 0805_M | CAP | 2 | 4.7uF
CAP |  | C75, C76, C77 | C 0805_L | CAP | 3 | 100nF
D 1N4148 | High Conductance Fast Diode | D1 | SOD-523 | D 1N4148 | 1
SS34 | DIODE LED | D2, D3 | DO-214AC-SMA | DIOLED_1 | 2
TVS | High Conductance Fast Diode | D4, D6, D7, D8, D9, D10, D11, D12, D13, D14, D15, D16, D17, D18, D19, D20, D21, D22, D23, D25, D26, D27, D28, D29, D30, D31, D32, D33, D34, D35, D36, D37, D38, D39, D40, D41, D42, D43, D44, D45, D46 | SOD-523 | D | 41
D 1N4148 | High Conductance Fast Diode | D5 | SOD-123 | D 1N4148 | 1
DC |  | DC1 | DC-005 | DC | 1
Comment |  | Designator6, Designator9 | touch X |  | 2
Comment |  | Designator7 | WASH X |  | 1
Comment |  | Designator8 | Pb X |  | 1
LED |  | DS1, DS2, DS3, DS4, DS5 | LED 0805B | LED | 5
CON2 |  | J1 | DG1282-5.0 | CON2 | 1
6.8uH |  | L1, L3 | L100 | INDUCTOR1_1 | 2
0805 | Resistor | L2 | R 0402_L | RES2 | 1 | 0
0805 | Resistor | L5, R53 | R 0805_L | RES2 | 2 | 0
LED3 | DIODE LED | LED1, LED2 | 0603-led | CP_DIOLED | 2
Speaker | Loudspeaker | LS1 | BEEP 5x9x5.5 | Speaker | 1
MicroUSB-DIP |  | MicroUSB-DIP1 | MICRO_USB_DIP | MicroUSB-DIP | 1
Header 2X2 | Header, 2-Pin, Dual row | P1, P34 | HDR2.54-LI-2x2P | Header 2X2 | 2
Header 2 | Header, 2-Pin | P2, P24, P25, P26 | HDR2.54-LI-2P | Header 2 | 4
Header 4 | Header, 4-Pin | P3 | KF2EDGK-2.54-WI-4P | Header 4 | 1
PO | Header, 4-Pin | P4, P8, P10, P12 | KF2EDGK-2.54-WI-4P | Header 4 | 4
USART2 | Header, 4-Pin | P5 | KF2EDGK-2.54-WI-4P | Header 4 | 1
CAN1 | Header, 4-Pin | P6, P28 | KF2EDGK-2.54-WI-4P | Header 4 | 2
USART6 | Header, 4-Pin | P7, P18, P21 | KF2EDGK-2.54-WI-4P | Header 4 | 3
USART3 | Header, 4-Pin | P9 | KF2EDGK-2.54-WI-4P | Header 4 | 1
USART4 | Header, 4-Pin | P11 | KF2EDGK-2.54-WI-4P | Header 4 | 1
ADC_IN4 | Header, 4-Pin | P13, P32, P33 | KF2EDGK-2.54-WI-4P | Header 4 | 3
Header 4 | Header, 4-Pin | P14, P15, P17, P19, P20, P22, P35, P36, P37, P38 | HDR2.54-LI-4P | Header 4 | 10
USART5 | Header, 4-Pin | P16 | KF2EDGK-2.54-WI-4P | Header 4 | 1
Header 20X2 | Header, 20-Pin, Dual row | P23, P27 | HDR2X20 | Header 20X2 | 2
Header 15X2 | Header, 15-Pin, Dual row | P29, P31 | HDR2X15 | Header 15X2 | 2
Header 6 | Header, 6-Pin | P30 | KF2EDGK-2.54-WI-6P | Header 6 | 1
OLED | Header, 4-Pin | P39 | HDR1X4 | Header 4 | 1
Header 10 | Header, 10-Pin | P40 | KF2EDGK-2.54-WI-10P | Header 10 | 1
8050 | NPN Bipolar Transistor | Q1, Q2, Q3, Q4 | SOT23-3L | NPN SOT | 4
RES2 | Resistor | R1, R2, R3, R4, R24, R26, R27, R28, R29, R77, R79, R80, R84 | R 0805_L | RES2 | 13 | 1K
0805 | Resistor | R6, R66, R67, R68, R69, R70, R71, R72, R73, R74 | R 0805_L | RES2 | 10 | 200R
0805 | Resistor | R7, R8, R9, R10, R12, R30 | R 0805_L | RES2 | 6 | 10K
0805 | Resistor | R11 | R 0805_L | RES2 | 1 | 40K
0805 | Resistor | R13 | R 0805_L | RES2 | 1 | 1K
10K |  | R14, R19 | 0603 | RES2 | 2
10.2K |  | R15, R20 | 0603 | RES2 | 2
1.91K |  | R16, R21 | 0603 | RES2 | 2
0805 | Resistor | R17 | R 0402_L | RES2 | 1 | 47
29.4K |  | R18, R22 | 0603 | RES2 | 2
RES2 | Resistor | R23, R25, R76, R78 | R 0805_L | RES2 | 4 | 10K
0805 | Resistor | R31, R33 | R 0805_L | RES2 | 2 | 22
0805 | Resistor | R32, R34 | R 0805_L | RES2 | 2 | 100
0805 | Resistor | R40, R45 | R 0805_L | RES2 | 2 | 0R
0805 | Resistor | R41 | R 0805_L | RES2 | 1 | 120
0805 | Resistor | R75 | R 0805_L | RES2 | 1
SW |  | S1 | TSW DIP-3*6*5 | SW | 1
SDCARD-M | TF卡槽 | SD1 | SDCARD-M | SDCARD-M | 1
STM32F407IGT6 | ARM Cortex-M4 32-bit MCU+FPU, 210 DMIPS, 1024 kB Flash, 192 kB Internal RAM, 140 I/Os, 176-pin LQFP, -40 to 85 degC, Tray | U1 | STM-LQFP176_N | STM32F407IGT6 | 1
TPS54331 |  | U2, U3 | SO08 | TPS54331 | 2
LM1117 |  | U4, U5 | SOT223 | LM1117 | 2
TJA1044GTK/3 |  | U6 | HVSON8 | TJA1044GTK/3 | 1
CH340G |  | U8 | SOP16_M | CH340G | 1
TYPE-C-31-M-12 |  | USBC1 | TYPE-C-USB-17 | TYPE-C-31-M-12 | 1
25M | 4脚晶振 | X1 | XTAL-3225 | XTAL-4 | 1
32.768KHz | 2脚晶振 | X2 | XTAL-3215A | XTAL-2 | 1
12M |  | X3 | OSC HC-49S | YX | 1

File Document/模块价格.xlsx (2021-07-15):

名称 | 价格 | 图片
边缘智能处理终端 | 3199 |  | 总计 | 17070.41
大数据终端显示器 | 11059
机载嵌入显示器 | 450.1
图像获取单元 | 570
音频单元 | 800
网络组网单元 | 188
STM32F4核心控制单元 | 500
ESP32物联网单元 | 44
测距传感器单元 | 46
压力传感器单元 | 36
血氧心率模块 | 23.99
5）非接触式测温模块 | 84.57
烟雾传感器单元 | 5.35
甲醛传感器单元 | 46
温湿度传感器单元 | 7.55
光照度传感器单元 | 3.65
空气污染检测传感器单元 | 7.2

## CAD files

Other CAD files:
Reference/非接触式测温传感器/c51_usart/output/main.obj
Reference/光照度传感器/测试程序/STC51/STC_BH1750/STC_BH1750.OBJ
Reference/环境温湿度传感器/YL-47测试程序/51_DHT11/51_DHT21.OBJ
Reference/光照度传感器/测试程序/STC51/STC_BH1750/STARTUP.OBJ
Reference/非接触式测温传感器/c51_usart/output/usart.obj
Reference/非接触式测温传感器/c51_usart/output/stc_it.obj

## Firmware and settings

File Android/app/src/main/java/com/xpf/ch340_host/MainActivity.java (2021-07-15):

package com.xpf.ch340_host;

import android.animation.AnimatorSet;
import android.animation.ObjectAnimator;
import android.app.PendingIntent;
import android.content.BroadcastReceiver;
import android.content.Context;
import android.content.Intent;
import android.content.IntentFilter;
import android.graphics.Color;
import android.hardware.usb.UsbDevice;
import android.hardware.usb.UsbDeviceConnection;
import android.hardware.usb.UsbManager;
import android.os.Build;
import android.os.Bundle;
import android.os.Handler;
import android.os.Message;
import android.support.annotation.RequiresApi;
import android.support.v7.app.AppCompatActivity;
import android.view.View;
import android.widget.ImageView;
import android.widget.TextView;
import android.widget.Toast;

import com.github.mikephil.charting.charts.LineChart;
import com.hoho.android.usbserial.driver.UsbSerialDriver;
import com.hoho.android.usbserial.driver.UsbSerialPort;
import com.hoho.android.usbserial.driver.UsbSerialProber;
import com.hoho.android.usbserial.util.SerialInputOutputManager;

import com.xpf.ch340_host.CH340.CH340Master;
import com.xpf.ch340_host.CH340.driver.InitCH340;
import com.xpf.ch340_host.CH340.runnable.BufferCallBack;
import com.xpf.ch340_host.CH340.runnable.ICallBack;
import com.xpf.ch340_host.CH340.utils.FileReadString;
import com.xpf.ch340_host.CH340.utils.MyFile;
import com.xpf.ch340_host.RingBuffer.CircleBuffer;
import com.xpf.ch340_host.UI.CirclePercentView;
import com.xpf.ch340_host.UI.DynamicLineChartManager;
import com.xpf.ch340_host.UI.UIOperation;
import com.zkk.view.rulerview.RulerView;

import java.io.FileReader;
import java.util.ArrayList;
import java.util.List;
import java.util.concurrent.ExecutorService;
import java.util.concurrent.Executors;


public class MainActivity extends AppCompatActivity implements InitCH340.IUsbPermissionListener {

    private boolean isFirst;//判断是否打开
    private static final String ACTION_USB_PERMISSION = "com.linc.USB_PERMISSION";
    // 手机根目录
    private static String ROOT_PATH = "";
    // 仪器高度
    private static int InstrumentHeight = 220;


    public static MainActivity mainActivity;

    public ImageView HeartImg;  // 心跳动画
    public ImageView FAS;       // 烟雾报警
    public TextView  HeartText;
    public TextView  PeopleTemperatureText;
    public TextView  BMI;
    public TextView  WenDuShow;
    public TextView  ShiDuShow;
    public TextView  LightShow;

    public CirclePercentView PeopleTemperature;
    public CirclePercentView BloodOxygen;
    public TextView          BloodOxygenText;

    public LineChart Heart;          // 血氧相关
    public LineChart Environmental;  // 温湿度
    public LineChart Light;          // 亮度

    public TextView LengthText;    // 测距
    public TextView PressureText;  // 压力

    public RulerView Pressure;   // 压力
    public RulerView Length;     // 测距

    public int Temp = 0;


    public static String WeightStr = "";  // 体重

    public DynamicLineChartManager HeartDynamicLineChartManager;            // 血氧相关
    public DynamicLineChartManager EnvironmentalDynamicLineChartManager;    // 温湿度
    public DynamicLineChartManager LightDynamicLineChartManager;            // 亮度

    List<Integer> HeartDatas;         // 心率图
    List<Integer> EnvironmentalDatas; // 环境图


    public static boolean startShow = false;
    public static int     number4heart = 0;
    public ICallBack iCallBack = new ICallBack() {
        @Override
        public void bufferData(final Agreement agreement) {
                runOnUiThread(new Runnable() {
                    @RequiresApi(api = Build.VERSION_CODES.M)
                    @Override
                    public void run() {

                        // 心率更新
                        if(agreement.HemoglobinWaveformTwo>280 || agreement.HemoglobinWaveformTwo<-20){
                            agreement.HemoglobinWaveformTwo = Temp;
                            agreement.HemoglobinWaveformOne = Temp;
                        }
                        HeartDatas = new ArrayList<>();
                        HeartDatas.add((int)(agreement.HemoglobinWaveformTwo));
                        HeartDatas.add((int)(agreement.HemoglobinWaveformOne));
                        Temp = (int)agreement.HemoglobinWaveformOne;
                        HeartDynamicLineChartManager.addEntry(HeartDatas,1000);

                        // 环境更新
                        EnvironmentalDatas = new ArrayList<>();
                        EnvironmentalDatas.add((int)agreement.EnvironmentTemperature);
                        EnvironmentalDatas.add((int)agreement.EnvironmentHumidity);
                        EnvironmentalDynamicLineChartManager.addEntry(EnvironmentalDatas,500);

                        // 亮度更新
                        LightDynamicLineChartManager.addEntry((int)(agreement.light)+50);

                        WenDuShow.setText("温度"+agreement.EnvironmentTemperature+"");
                        ShiDuShow.setText("湿度"+agreement.EnvironmentHumidity+"");
                        LightShow.setText("亮度:"+agreement.light);

                        // 测距更新
                        int length = (int)(InstrumentHeight-agreement.distance);
                        Length.setValue(length,10,200,1);
                        LengthText.setText("身高:"+0+"cm");
                        // 压力更新
                        if(!WeightStr.equals(""))
                        {
                            float WeightNum = 0;
                            try{
                                 WeightNum = Float.valueOf(WeightStr);
                            }catch (Exception e){
                                WeightNum = 0;
                            }

                            if(WeightNum > 10)
                            {
                                Pressure.setValue(WeightNum,0,200,1);
                                PressureText.setText("体重:"+WeightNum+"kg");
                                LengthText.setText("身高:"+length+"cm");
                                float lengthSqrt = (length/(float)100.0)*(length/(float)100.0);
                                int bmi = (int)((WeightNum)/lengthSqrt);
                                if(bmi<19){
                                    BMI.setText("BMI指数:"+bmi+"("+"偏瘦"+")");
                                    BMI.setTextColor(Color.WHITE);
                                }else if(bmi>=19&&bmi<=24){
                                    BMI.setText("BMI指数:"+bmi+"("+"正常"+")");
                                    BMI.setTextColor(Color.GREEN);
                                }else if(bmi>24&&bmi<28){
                                    BMI.setText("BMI指数:"+bmi+"("+"过重"+")");
                                    BMI.setTextColor(Color.YELLOW);
                                }else if(bmi>=28){
                                    BMI.setText("BMI指数:"+bmi+"("+"肥胖"+")");
                                    BMI.setTextColor(Color.RED);
                                }
                            }else {
                                BMI.setText("");
                                Pressure.setValue(agreement.pressure,0,200,1);
                                PressureText.setText("体重:"+(agreement.pressure)+"kg");
                            }

                        }

                        if(!startShow){
                            // 开始检测是否应开始测量
                            if(agreement.HemoglobinWaveformTwo>160 || agreement.HemoglobinWaveformTwo<140){
                                startShow = true;
                            }
                            HeartText.setText(0+"");
                            BloodOxygen.setPercentage(0);
                            BloodOxygenText.setText(0+"%");
                            number4heart = 0;

                        }
                        // 开始进行心率测量
                        else {
                            // 心率更新
                            if(agreement.heartRate < 0)agreement.heartRate*=-1;
                            if(agreement.heartRate > 50)
                            {
                                HeartText.setText(agreement.heartRate+"");
                            }

                            // 血氧
                            if(agreement.OxygenSaturation>10){
                                BloodOxygen.setPercentage((float)(90+((int)agreement.OxygenSaturation*0.1)));
                                BloodOxygenText.setText(90+((int)agreement.OxygenSaturation*0.1)+"%");
                                number4heart++;
                                if(number4heart > 500){
                                    startShow = false;
                                }
                            }else{
                                BloodOxygen.setPercentage(0);
                                BloodOxygenText.setText(0+"%");
                            }
                        }

                        // 判断手指是否按压上去了
                        if(true){

                        }else{
                             }


                        // 人体测温
                        if(agreement.PeopleTemperature >= 37){
                            PeopleTemperatureText.setTextColor(Color.RED);
                        }else{
                            PeopleTemperatureText.setTextColor(getApplicationContext().getColor(R.color.people_wendu));
                        }
                        PeopleTemperature.setPercentage(agreement.PeopleTemperature);
                        PeopleTemperatureText.setText(Util.TempOperation(agreement.PeopleTemperature)+"°C");



                        if(agreement.EnvironmentSmoke==1){
                            FAS.setVisibility(View.INVISIBLE);
                        }else{
                            FAS.setVisibility(View.VISIBLE);
                        }

                    }
                });
        }
    };


    @Override
    protected void onCreate(Bundle savedInstanceState) {
        super.onCreate(savedInstanceState);
        setContentView(R.layout.activity_main);

//        CrashReport.initCrashReport(getApplicationContext(),"902fe8c1cb",true);
        initView();
        test();
        new Thread(new Runnable() {
            @Override
            public void run() {
                test1();
            }
        }).start();


        Agreement.init();
        CircleBuffer.init(1024);
        new BufferCallBack(iCallBack).start();

        initData();
    }
    public AnimatorSet set1;
    @RequiresApi(api = Build.VERSION_CODES.M)
    private void initView() {
        UIOperation.SetFullScreen(this);
        Heart         = findViewById(R.id.heart);
        Environmental = findViewById(R.id.environmental);
        Light         = findViewById(R.id.light);
        Pressure      = findViewById(R.id.pressure);
        Length        = findViewById(R.id.length);
        LengthText    = findViewById(R.id.length_text);
        PressureText  = findViewById(R.id.pressure_text);
        HeartImg      = findViewById(R.id.heart_img);
        HeartText     = findViewById(R.id.heart_text);
        FAS           = findViewById(R.id.fas);
        BMI           = findViewById(R.id.bmi);
        LightShow     = findViewById(R.id.light_show_2);
        WenDuShow     = findViewById(R.id.wendu_show);
        ShiDuShow     = findViewById(R.id.shidu_show);
        PeopleTemperature     = findViewById(R.id.people_temperature);
        PeopleTemperatureText = findViewById(R.id.people_temperature_text);
        BloodOxygen           = findViewById(R.id.blood_oxygen);
        BloodOxygenText       = findViewById(R.id.blood_oxygen_text);


        // 初始化根目录
        ROOT_PATH = MyFile.configure;
        System.out.println("日志:"+ROOT_PATH);

        // 读取高度
        InstrumentHeight = new Integer(FileReadString.read(ROOT_PATH));
        InstrumentHeight = 210;
        /********************************心跳动画********************************/
             ObjectAnimator anim1 = ObjectAnimator.ofFloat(HeartImg,"scaleX",1.2f,0.8f);
             anim1.setRepeatCount(-1);
             ObjectAnimator anim2 = ObjectAnimator.ofFloat(HeartImg,"scaleY",1.2f,0.8f);
             anim2.setRepeatCount(-1);
             AnimatorSet set = new AnimatorSet();
             set.play(anim1).with(anim2);
             set.setDuration(1000);
             set.start();
        /********************************心跳动画********************************/
        // 播放动画
        ObjectAnimator anim3 = ObjectAnimator.ofFloat(FAS,"scaleX",1.2f,0.8f);
        anim3.setRepeatCount(-1);
        ObjectAnimator anim4 = ObjectAnimator.ofFloat(FAS,"scaleY",1.2f,0.8f);
        anim4.setRepeatCount(-1);
        set1 = new AnimatorSet();
        set1.play(anim3).with(anim4);
        set1.setDuration(1000);
        set1.start();
        /********************************血氧********************************/
        BloodOxygen.setStartColor(getApplicationContext().getColor(R.color.start1));
        BloodOxygen.setEndColor(getApplicationContext().getColor(R.color.end1));
        /********************************测温********************************/


        Length.setValue(10, 10, 80, 1);
        Pressure.setValue(0, 0, 200, (float) 0.1);


        List<String>  HeartNames          = new ArrayList<>();
        List<String>  EnvironmentalNames  = new ArrayList<>();

        List<Integer> HeartColors         = new ArrayList<>();
        List<Integer> EnvironmentalColors = new ArrayList<>();


        PressureText.setText("体重:0.0kg");

        HeartNames.add("血红蛋白1");
        HeartNames.add("血红蛋白2");

        HeartColors.add(Color.RED);
        HeartColors.add(Color.CYAN);

        EnvironmentalNames.add("温度");
        EnvironmentalNames.add("湿度");

        EnvironmentalColors.add(Color.GREEN);
        EnvironmentalColors.add(Color.BLUE);


        Heart.setBackgroundColor(Color.argb(30,176,224,230));
        Environmental.setBackgroundColor(Color.argb(60,30,144,255));
        Light.setBackgroundColor(Color.argb(60,160,102,211));

        // 心率曲线初始化
        HeartDynamicLineChartManager         = new DynamicLineChartManager(Heart,HeartNames,HeartColors);
        HeartDynamicLineChartManager.setYAxis(300, -100, 10);
        HeartDynamicLineChartManager.setDescription("血红蛋白");

        // 环境温湿度曲线初始化
        EnvironmentalDynamicLineChartManager = new DynamicLineChartManager(Environmental,EnvironmentalNames,EnvironmentalColors);
        EnvironmentalDynamicLineChartManager.setYAxis(99,0,10);
        EnvironmentalDynamicLineChartManager.setDescription("");

        // 亮度曲线初始化
        LightDynamicLineChartManager         = new DynamicLineChartManager(Light,"亮度",Color.YELLOW);
        LightDynamicLineChartManager.setYAxis(2000, 0, 10);
        LightDynamicLineChartManager.setDescription("");

        mainActivity = this;


    }


    private void initData() {
        InitCH340.setListener(this);
        if (!isFirst) {
            isFirst = true;
            // 初始化 ch340-library
//            CH340Master.initialize(MyApplication.getContext());
        }
    }

    @Override
    public void result(boolean isGranted) {
        if (!isGranted) {
            PendingIntent mPermissionIntent = PendingIntent.getBroadcast(this, 0, new Intent(ACTION_USB_PERMISSION), 0);
            InitCH340.getmUsbManager().requestPermission(InitCH340.getUsbDevice(), mPermissionIntent);
        }
    }

    @Override
    protected void onResume() {
        super.onResume();
        IntentFilter usbFilter = new IntentFilter();
        usbFilter.addAction(ACTION_USB_PERMISSION);
//        registerReceiver(mUsbReceiver, usbFilter);
    }


    private final ExecutorService mExecutor = Executors.newSingleThreadExecutor();
    private SerialInputOutputManager mSerialIoManager;

    private final SerialInputOutputManager.Listener mListener =
            new SerialInputOutputManager.Listener() {
                @Override
                public void onRunError(Exception e) {
                }

                @Override
                public void onNewData(final byte[] data) {
                    //TODO 新的数据
                    for (int i=0;i<data.length;i++){
                        CircleBuffer.getRingBuffer().putElement(data[i]);
                    }
                }
            };



    private final ExecutorService mExecutor1 = Executors.newSingleThreadExecutor();
    private SerialInputOutputManager mSerialIoManager1;

    private final SerialInputOutputManager.Listener mListener1 =
            new SerialInputOutputManager.Listener() {
                @Override
                public void onRunError(Exception e) {
                }

                @Override
                public void onNewData(final byte[] data) {
                    //TODO 新的数据
                    try{
                        String result = new String(data,"UTF-8");
                        int index = result.indexOf(',');
                        WeightStr = result.substring(0,index);
                    }catch (Exception e){

                    }

                }
            };


    public void test(){

        try{
            // Find all available drivers from attached devices.
            UsbManager manager = (UsbManager) getSystemService(Context.USB_SERVICE);
            List<UsbSerialDriver> availableDrivers = UsbSerialProber.getDefaultProber().findAllDrivers(manager);
            if (availableDrivers.isEmpty()) {
                return;
            }

            // Open a connection to the first available driver.
            UsbSerialDriver driver = availableDrivers.get(0);
            System.out.println("日志:"+driver.getDevice().getDeviceId());
            if(driver.getDevice().getDeviceId()<3000){
                driver = availableDrivers.get(1);
            }
            UsbDeviceConnection connection = manager.openDevice(driver.getDevice());
            if (connection == null) {
                // add UsbManager.requestPermission(driver.getDevice(), ..) handling here
                return;
            }

            UsbSerialPort port = driver.getPorts().get(0); // Most devices have just one port (port 0)
            port.open(connection);
            port.setParameters(115200, 8, UsbSerialPort.STOPBITS_1, UsbSerialPort.PARITY_NONE);
            mSerialIoManager = new SerialInputOutputManager(port, mListener);//添加监听

            mExecutor.submit(mSerialIoManager);

        }catch (Exception e){

        }

    }



    public void test1(){

        try{
            // Find all available drivers from attached devices.
            UsbManager manager = (UsbManager) getSystemService(Context.USB_SERVICE);
            List<UsbSerialDriver> availableDrivers = UsbSerialProber.getDefaultProber().findAllDrivers(manager);
            if (availableDrivers.isEmpty()) {
                return;
            }

            // Open a connection to the first available driver.
            UsbSerialDriver driver = availableDrivers.get(1);
            System.out.println("日志:"+driver.getDevice().getDeviceId());
            if(driver.getDevice().getDeviceId()>3000){
                driver = availableDrivers.get(0);
            }
            UsbDeviceConnection connection = manager.openDevice(driver.getDevice());
            if (connection == null) {
                // add UsbManager.requestPermission(driver.getDevice(), ..) handling here
                return;
            }
            UsbSerialPort port = driver.getPorts().get(0); // Most devices have just one port (port 0)
            port.open(connection);
            port.setParameters(9600, 8, UsbSerialPort.STOPBITS_1, UsbSerialPort.PARITY_NONE);
            mSerialIoManager1 = new SerialInputOutputManager(port, mListener1);//添加监听

            mExecutor1.submit(mSerialIoManager1);

        }catch (Exception e){

        }

    }


//    private final BroadcastReceiver mUsbReceiver = new BroadcastReceiver() {
//        public void onReceive(Context context, Intent intent) {
//            String action = intent.getAction();
//            if (ACTION_USB_PERMISSION.equals(action)) {
//                synchronized (this) {
//                    UsbDevice device = intent.getParcelableExtra(UsbManager.EXTRA_DEVICE);
//                    if (intent.getBooleanExtra(UsbManager.EXTRA_PERMISSION_GRANTED, false)) {
//                        if (device != null) {
//                            Toast.makeText(MainActivity.this, "EXTRA_PERMISSION_GRANTED~", Toast.LENGTH_SHORT).show();
//                            InitCH340.loadDriver(MyApplication.getContext(), InitCH340.getmUsbManager());
//                        }
//                    } else {
//                        Toast.makeText(MainActivity.this, "EXTRA_PERMISSION_GRANTED null!", Toast.LENGTH_SHORT).show();
//                    }
//                }
//            }
//        }
//    };

    @Override
    protected void onDestroy() {
        super.onDestroy();
//        unregisterReceiver(mUsbReceiver);
    }
}

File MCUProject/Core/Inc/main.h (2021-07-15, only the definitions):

#define OLED_SCL_Pin GPIO_PIN_7
#define OLED_SCL_GPIO_Port GPIOH
#define OLED_SDA_Pin GPIO_PIN_8
#define OLED_SDA_GPIO_Port GPIOH
#define HX711_SDA_Pin GPIO_PIN_12
#define HX711_SDA_GPIO_Port GPIOC
#define HX711_SCL_Pin GPIO_PIN_2
#define HX711_SCL_GPIO_Port GPIOD

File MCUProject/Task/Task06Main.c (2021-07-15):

/**
  ******************************************************************************
  * File Name          : Task05Main.c
  * Description        : Code for freeRTOS Task06 Application
  ******************************************************************************
  * @author  kmakise-zdd171
  * @version V1.0.0
  * @date    2021-1-28
  * @brief   task5
	******************************************************************************
  * @attention
  *
  * All rights reserved.
  *
  * Communication of sensor data update of Android Board 
  ******************************************************************************
  */
/* Includes ------------------------------------------------------------------*/
#include "FreeRTOS.h"
#include "task.h"
#include "main.h"
#include "cmsis_os.h"
#include "Task06Main.h"

#include "Task01Main.h"
#include "stdio.h"
#include "string.h"
#include "usart.h"
#include "crc.h"

uint8_t g_SendDataTemp[100];  //change temp
uint8_t g_SendDataRead[100];  //send to update

void setDataToUpdate(DataTypedef dt,void * val)
{
	//u16 data
	union 
	{
		uint8_t arr[2];
		uint16_t data;
	}datau16;
	
	//float32 data
	union 
	{
		uint8_t arr[4];
		float	data;
	}dataflt32;
	
	switch(dt)
	{
		case DISTANCE:	//测距				4 	u8
		{
			g_SendDataTemp[4] = *(uint8_t *)val;
			break;
		}
		case PRESSURE:	//压力				5 	u16
		{ 
			datau16.data = *((uint16_t *)val);
			memcpy(&g_SendDataTemp[5],datau16.arr,2);
			break;
		}
		case HRTIMES:		//心率				7 	u8
		{
			g_SendDataTemp[7] = *(uint8_t *)val;
			break;
		}
		case SPO2PCT:		//血氧饱和度	8		f32
		{
			dataflt32.data = *((float *)val);
			memcpy(&g_SendDataTemp[8],dataflt32.arr,4);
			break;
		}
		case HBDATA1:		//血氧波形1		12	f32
		{
			dataflt32.data = *((float *)val);
			memcpy(&g_SendDataTemp[12],dataflt32.arr,4);
			break;
		}
		case HBDATA2:		//血氧波形2		16	f32
		{
			dataflt32.data = *((float *)val);
			memcpy(&g_SendDataTemp[16],dataflt32.arr,4);
			break;
		}
		case HMTEMP:		//体温				20	f32	
		{
			dataflt32.data = *((float *)val);
			memcpy(&g_SendDataTemp[20],dataflt32.arr,4);
			break;
		}
		case SMOKING:		//烟雾				24  u8
		{
			g_SendDataTemp[24] = *(uint8_t *)val;
			break;
		}
		case ENVTEMP:		//温度				25	u8
		{
			g_SendDataTemp[25] = *(uint8_t *)val;
			break;
		}
		case ENVHUMT:		//湿度				26	u8
		{
			g_SendDataTemp[26] = *(uint8_t *)val;
			break;
		}
		case LIGHTPW:		//光照				27	u16
		{
			datau16.data = *((uint16_t *)val);
			memcpy(&g_SendDataTemp[27],datau16.arr,2);
			break;
		}
		default:break;
	}
}

void sendDataToUpdate(void)
{
	memcpy(g_SendDataRead,g_SendDataTemp,29);
	g_SendDataRead[0] = 0x5A;
	g_SendDataRead[1] = 0xA5;
	g_SendDataRead[2] = 0x01;
	g_SendDataRead[3] = 24;
	
	uint16_t crc16 = CalCRC16(g_SendDataRead,29);
	g_SendDataRead[29] = (crc16 >> 8) &0xff;
	g_SendDataRead[30] = crc16 &0xff;
	
	HAL_UART_Transmit_DMA(&huart1,g_SendDataRead,31);
	HAL_UART_Transmit_DMA(&huart2,g_SendDataRead,31);
}

//50Hz Task Long Time

void Task06Main(void)
{
	
	//wait for hardware configure
	while(getHardwareState());
	
	
	for(;;)
	{		
		sendDataToUpdate();
		
		osDelay(20);
	}
}

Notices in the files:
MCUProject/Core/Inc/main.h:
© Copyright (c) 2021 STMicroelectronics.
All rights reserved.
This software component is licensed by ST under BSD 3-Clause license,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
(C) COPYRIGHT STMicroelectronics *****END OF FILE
